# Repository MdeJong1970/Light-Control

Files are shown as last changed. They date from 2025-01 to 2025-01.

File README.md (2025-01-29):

# Light-Control
New Light Control

The board and the LEDs are powered by the servo connection.

The LEDs have a common power connection

The current software has the following functions:
- HeadLight, TailLeft & TailRight LEDs on/off, controlled with the LIGHT CRTL SERVO channel
- Blinking of the TurnLeft & TurnRight LEDs, controlled with the STEER SERVO channel
- ReverseLight LEDs switched on when driving backwards, controlled with the SPEED SERVO channel
- the TailLeft & TailRight LEDs are in sync with the TurnLeft & TurnRight

top view of the board
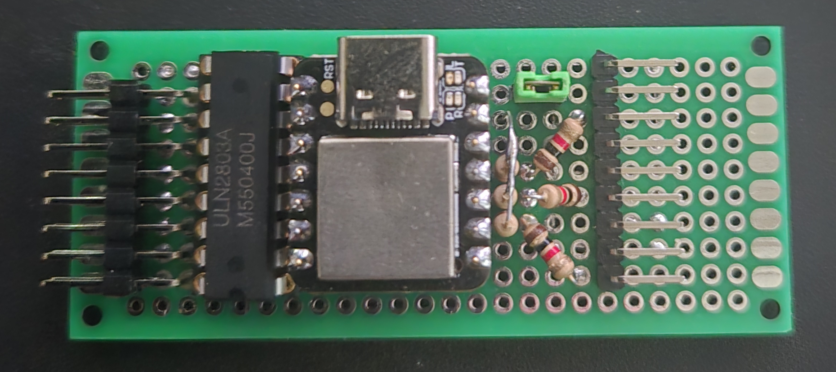
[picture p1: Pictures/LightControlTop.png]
top view of the board


bottom view of the board
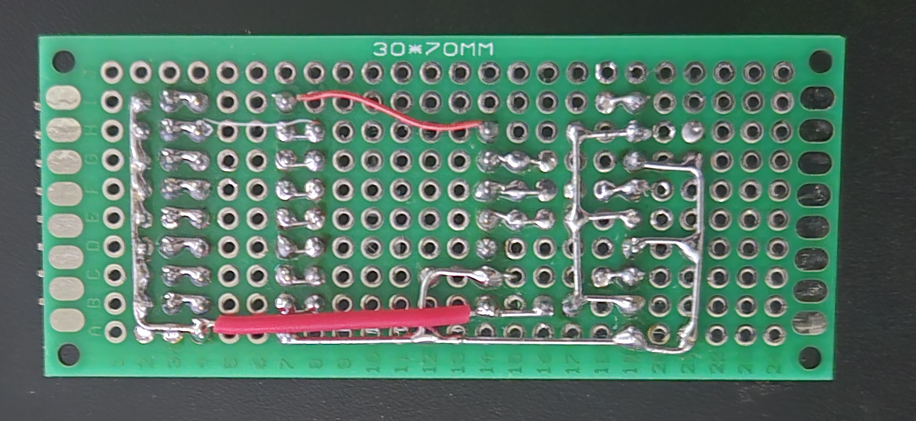
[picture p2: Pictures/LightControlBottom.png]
bottom view of the board


The size is 30mm x 70mm.

## Used components:
- Seeed Studio XIAO SAMD21
- ULN2803A, driver 8 channels for LEDs
- 3 resistors 1K
- 3 resistors 2K
- 2x8 pin header for LEDs
- 1x9 pin header for servos

## LED connection:
- pin D0 - 5mm white HeadLight LEDs
- pin D1 - Reverse - 3mm white LEDs on tail panel
- pin D2 - Left turn signals
- pin D3 - Right turn signals
- pin D4 - Tail lamp Left
- pin D5 - Tail lamp Right
- pin D6 - Break lamp

## Servo connection:
- pin D8  - Forward/Backward channel
- pin D9  - Steering channel
- pin D10 - HeadLight channel 

## Connection of the board

Connection of the board
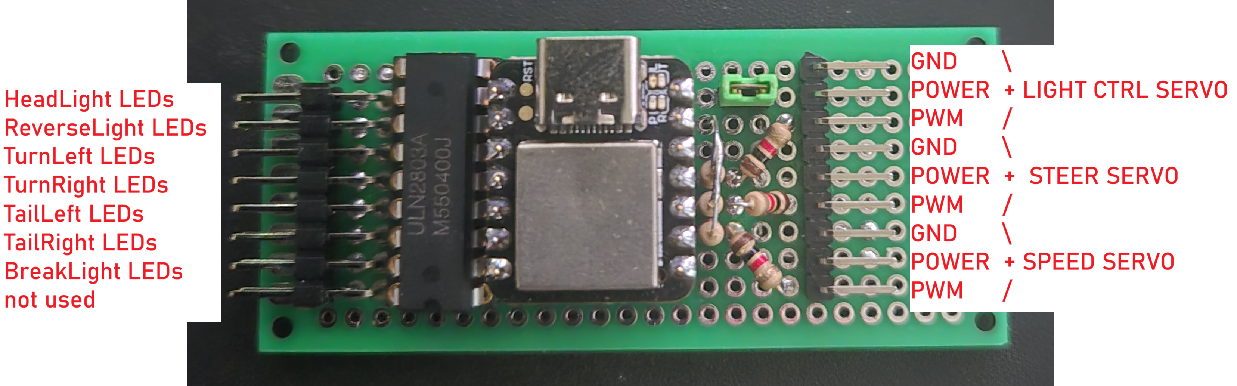
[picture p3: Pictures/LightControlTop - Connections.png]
Connection of the board


Connection of the LEDs
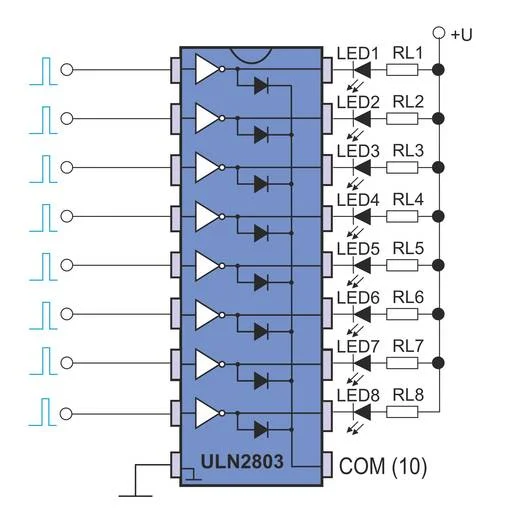
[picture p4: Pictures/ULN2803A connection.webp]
Connection of the LEDs


## Small holder for the board

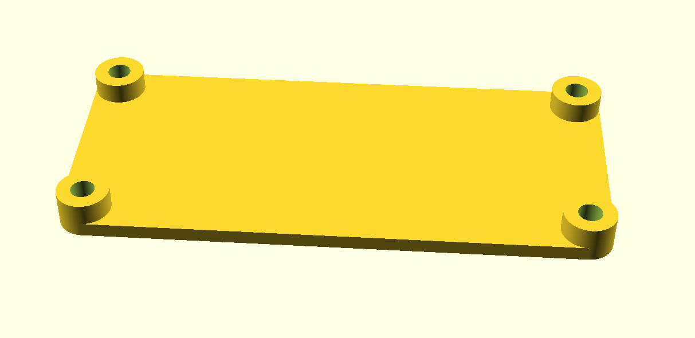
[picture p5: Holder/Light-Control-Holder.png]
Small holdder for the board


Designed with OpenSCAD (scad file available), STL file available.

To be used with brass thread inserts M2, outer diameter 3.2 mm, max length 5mm.

The schematic will follow.
First version of the firmware.

Usefull Links:
https://wiki.seeedstudio.com/Seeeduino-XIAO/

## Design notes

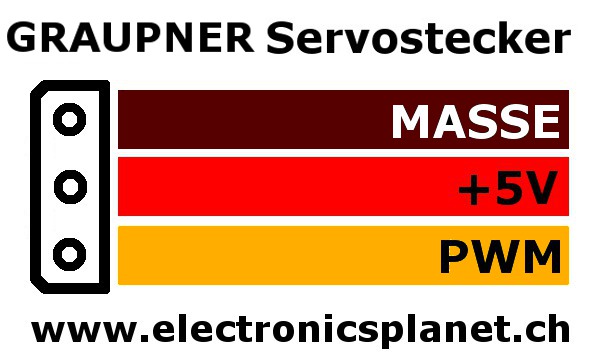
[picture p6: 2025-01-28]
Pictures/graupner.jpg

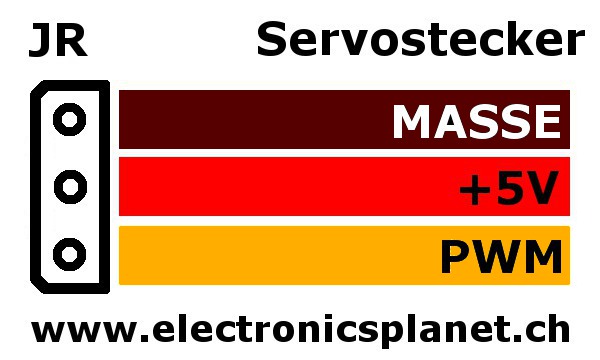
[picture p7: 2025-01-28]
Pictures/jr.jpg

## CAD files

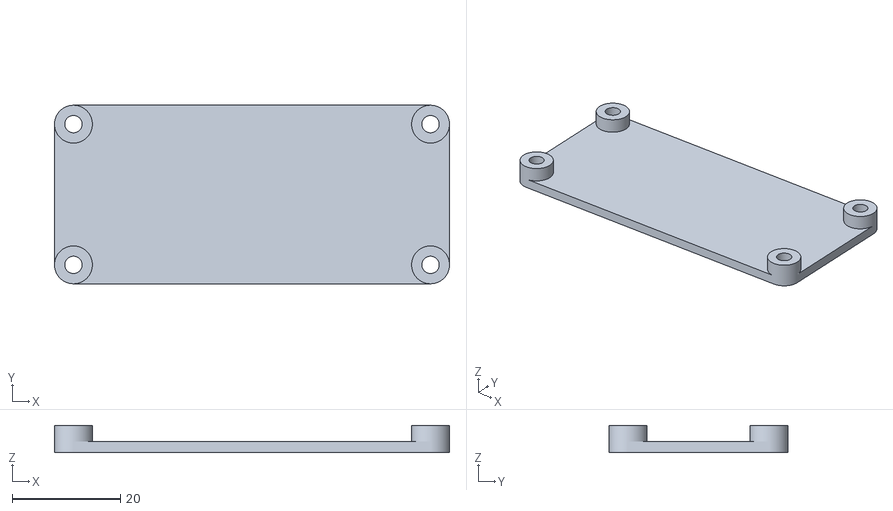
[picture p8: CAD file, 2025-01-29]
Holder/Light-Control-Holder.stl
73.0 x 33.0 x 5.00

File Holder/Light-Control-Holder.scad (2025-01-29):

$fn=250;

difference()
{
    union()
    {
        //translate([0,0,1]) cube( [73,33,2], center = true );
        hull()
        {
            translate([33,13,0]) cylinder (d=7,h=2);
            translate([33,-13,0]) cylinder (d=7,h=2);
            translate([-33,13,0]) cylinder (d=7,h=2);
            translate([-33,-13,0]) cylinder (d=7,h=2);
        }
        translate([33,13,0]) cylinder (d=7,h=5);
        translate([33,-13,0]) cylinder (d=7,h=5);
        translate([-33,13,0]) cylinder (d=7,h=5);
        translate([-33,-13,0]) cylinder (d=7,h=5);
    }
    
    translate([33,13,-1]) cylinder (d=3.2,h=7);
    translate([33,-13,-1]) cylinder (d=3.2,h=7);
    translate([-33,13,-1]) cylinder (d=3.2,h=7);
    translate([-33,-13,-1]) cylinder (d=3.2,h=7);    
}

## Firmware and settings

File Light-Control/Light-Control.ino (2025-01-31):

#include <stdio.h>
#include <string.h>
#include <stdlib.h>
#include <stdbool.h>
#include <Servo.h>

typedef enum
{
  SERVO_LEFT = 1,
  SERVO_CENTRAL = 2,
  SERVO_RIGHT = 3
} servo_pos_t;

#define SERVO_LOW  1400
#define SERVO_HIGH 1600
#define SERVO_MIN  1000
#define SERVO_MAX  2200

#define LED_ON HIGH
#define LED_OFF LOW

#define TURN_PERIODE 25000

// PPM read from receiver
#define speedPPM D8       //PPM input D8, Forward/Backward channel
#define steerPPM D9       //PPM input D9, Steering channel
#define Light_btnPPM D10  //PPM input D10, HeadLight channel 

// Numbers of pins on Arduino Micro for LEDs control
#define HeadLight D0      // pin D0 - 5mm white HeadLight LEDs
#define ReverseLight D1   // pin D1 - Reverse - 3mm white LEDs on tail panel
#define TurnLeft D2       // pin D2 - Left turn signals
#define TurnRight D3      // pin D3 - Right turn signals
#define TailLeft D4       // pin D4 - Tail lamp Left
#define TailRight D5      // pin D5 - Tail lamp Right
#define BreakLight D6     // pin D6 - Break lamp

#define HeadLightServo D7 // pin D6 - Head Light Cover Servo
#define HEAD_LIGHT_OPEN 0
#define HEAD_LIGHT_CLOSED 90

volatile servo_pos_t speed_servo;
volatile servo_pos_t steer_servo;
volatile servo_pos_t Light_btn_servo;

// Head Light Cover Servo
Servo HeadLight_servo;

// Variables for reading signals from receiver
volatile unsigned long lt1, ct1, ms_speed, tmp1;
volatile unsigned long lt2, ct2, ms_steer,tmp2;
volatile unsigned long lt3, ct3, ms_Light_btn, tmp3;

// Variables for Head light, turn signals, reverse
volatile bool light_on;
volatile bool reverse_on;
volatile bool turn_left;
volatile bool turn_right;

// variable for blinking timing
volatile unsigned long turn_left_time;
volatile unsigned long turn_right_time;

servo_pos_t eval_servo( unsigned long servo_value )
{
  servo_pos_t ret_value;

  ret_value = SERVO_CENTRAL;

  if( servo_value < SERVO_LOW )
  {
    ret_value = SERVO_LEFT;
  }
  if( servo_value > SERVO_HIGH )
  {
    ret_value = SERVO_RIGHT;
  }

  return( ret_value );
}

void setup(){

  //Set pin modes for servo connection
  pinMode(steerPPM, INPUT_PULLUP);
  pinMode(speedPPM, INPUT_PULLUP);
  pinMode(Light_btnPPM, INPUT_PULLUP);

  //Set pin modes for LEDs
  pinMode (HeadLight, OUTPUT);
  pinMode (ReverseLight, OUTPUT);
  pinMode (TurnLeft, OUTPUT);
  pinMode (TurnRight, OUTPUT);
  pinMode (TailLeft, OUTPUT);
  pinMode (TailRight, OUTPUT);
  pinMode (BreakLight, OUTPUT);

  //Set pins state on the beginning
  digitalWrite (HeadLight, LOW);
  digitalWrite (ReverseLight, LOW);
  digitalWrite (TurnLeft, LOW);
  digitalWrite (TurnRight, LOW);
  digitalWrite (TailLeft, LOW);
  digitalWrite (TailRight, LOW);
  digitalWrite (BreakLight, LOW);

  digitalWrite (steerPPM, HIGH);
  digitalWrite (speedPPM, HIGH);
  digitalWrite (Light_btnPPM, HIGH);

  //attach PPM interrupt service routines
  attachInterrupt( digitalPinToInterrupt(steerPPM), steerPPM_int, CHANGE);
  attachInterrupt( digitalPinToInterrupt(speedPPM), speedPPM_int, CHANGE);
  attachInterrupt( digitalPinToInterrupt(Light_btnPPM), Light_btnPPM_int, CHANGE);

  // attach HeadLight servo 
  HeadLight_servo.attach(HeadLightServo);

  speed_servo = SERVO_CENTRAL;
  steer_servo = SERVO_CENTRAL;
  Light_btn_servo = SERVO_CENTRAL;
}

// Main cycle
void loop()
{
  //convert servo puls values to servo status
  speed_servo = eval_servo( ms_speed );
  steer_servo = eval_servo( ms_steer );
  Light_btn_servo = eval_servo( ms_Light_btn );

  //evaluate the servo status
  if( Light_btn_servo == SERVO_RIGHT )
  {
    light_on = true;
  }
  else
  {
    light_on = false;
  }

  if( speed_servo == SERVO_RIGHT )
  {
    reverse_on = true;
  }
  else
  {
    reverse_on = false;
  }

  if( steer_servo == SERVO_RIGHT )
  {
    turn_left = true;
  }
  else
  {
    turn_left = false;
  }

  if( steer_servo == SERVO_LEFT )
  {
    turn_right = true;
  }
  else
  {
    turn_right = false;
  }

  //switch on head light
  if( light_on == true )
  {
    digitalWrite( HeadLight, HIGH );
    HeadLight_servo.write( HEAD_LIGHT_OPEN );
    if( turn_left == false )
    {
      digitalWrite( TailLeft, HIGH );
    }
    if( turn_right == false )
    {
      digitalWrite( TailRight, HIGH );
    }
  }
  else
  {
    digitalWrite( HeadLight, LOW );
    HeadLight_servo.write( HEAD_LIGHT_CLOSED );
    if( turn_left == false )
    {
      digitalWrite( TailLeft, LOW );
    }
    if( turn_right == false )
    {
      digitalWrite( TailRight, LOW );
    }
  }

  //switch on reverse light
  if( reverse_on == true )
  {
    digitalWrite( ReverseLight, HIGH );
  }
  else
  {
    digitalWrite( ReverseLight, LOW );
  }
  
  //Handle blinking left timing
  if( turn_left == true )
  {
    turn_left_time++;
    if( turn_left_time > TURN_PERIODE)
    {
      turn_left_time = 0;
    }
  }
  else
  {
    turn_left_time = 0;
  }

  //Handle blinking right timing
  if( turn_right == true )
  {
    turn_right_time++;
    if( turn_right_time > TURN_PERIODE)
    {
      turn_right_time = 0;
    }
  }
  else
  {
    turn_right_time = 0;
  }

  //switch on Turn Left
  if( turn_left == true )
  {
    if( turn_left_time < TURN_PERIODE/2 )
    {
      digitalWrite( TurnLeft, HIGH );
      digitalWrite( TailLeft, HIGH );
    }
    else
    {
      digitalWrite( TurnLeft, LOW );
      digitalWrite( TailLeft, LOW );
    }
  }
  else
  {
    digitalWrite( TurnLeft, LOW );
    if( light_on == true )
    {
      digitalWrite( TailLeft, HIGH );
    }
    else
    {
      digitalWrite( TailLeft, LOW );
    }
  }

  //switch on Turn Right
  if( turn_right == true )
  {
        if( turn_right_time < TURN_PERIODE/2 )
    {
      digitalWrite( TurnRight, HIGH );
      digitalWrite( TailRight, HIGH );
    }
    else
    {
      digitalWrite( TurnRight, LOW );
      digitalWrite( TailRight, LOW );
    }
  }
  else
  {
    digitalWrite( TurnRight, LOW );
    if( light_on == true )
    {
      digitalWrite( TailRight, HIGH );
    }
    else
    {
      digitalWrite( TailRight, LOW );
    }
  }  
}

// Reading signals from 3 channels
void speedPPM_int() 
{    // PPM read interrupt
  ct1 = micros(); // read current time
  ms_speed=ct1-lt1; // ms = current time - last time
  lt1=ct1; // last time
  if( (ms_speed>SERVO_MAX) || (ms_speed<SERVO_MIN) )
  {
    ms_speed=tmp1;
  }
  tmp1=ms_speed;
}    
void steerPPM_int() 
{
  ct2 = micros();
  ms_steer=ct2-lt2;
  lt2=ct2;
  if( (ms_steer>SERVO_MAX) || (ms_steer<SERVO_MIN) )
  {
    ms_steer=tmp2;
  }
  tmp2=ms_steer;
}
void Light_btnPPM_int() 
{
  ct3 = micros();
  ms_Light_btn=ct3-lt3;
  lt3=ct3; // last time
  if( (ms_Light_btn>SERVO_MAX) || (ms_Light_btn<SERVO_MIN) )
  {
    ms_Light_btn=tmp3;
  }
  tmp3=ms_Light_btn;
}

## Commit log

2025-01-29 Add board holder
    [Light-Control-Holder.scad, Light-Control-Holder.stl]
2025-01-29 add picture of the board holder
2025-01-30 Added the servo control for the Head Light Cover
